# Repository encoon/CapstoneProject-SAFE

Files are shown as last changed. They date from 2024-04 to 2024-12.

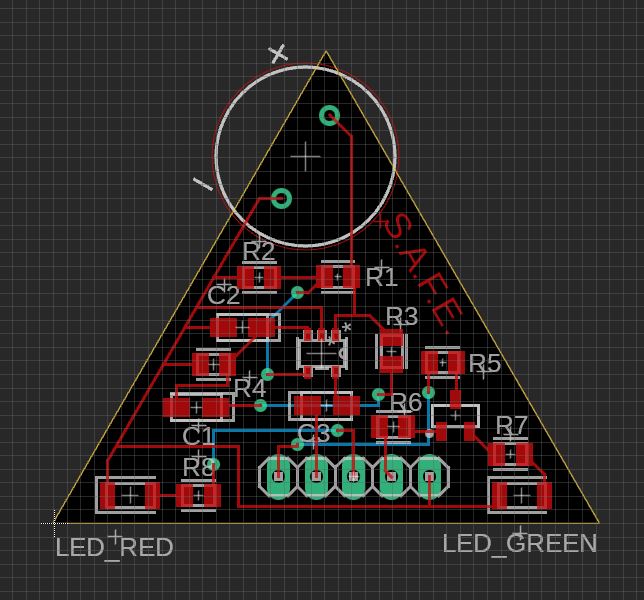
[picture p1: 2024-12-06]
AdditionalParts/AlarmingCircuitPCBDesign/Screenshot_AlarmingCircuit_PCB.JPG

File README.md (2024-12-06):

# CapstoneProject-SAFE
University of Utah capstone project, team SAFE repository<br/>
Project started in Feb 2024.
Demo day on 12/06 2024.

## Content
Team SAFE has been made up for a project making a product that determines the fatigue point of the muscle. We are using an EMG sensor from a company called 'Myoware', using sesnor Myoware 2.0. The fatigue point gets calculated by using fatigue coefficient by using raspberry pi 4, a grove base hat inverter, and alerts the user with a designed alerting circuit PCB. Refer to the block diagram below.

## Architecture Diagram
Diagram of the Block Diagram

### Members
Taehoon Kim<br/>
Nicholas Eloff<br/>
Thomas Green<br/>
Inhyup Lee

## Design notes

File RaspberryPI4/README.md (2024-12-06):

This folder contains the following files:
    Actual python codes for the project
    Text file that are helpful with the python codes
    raspberrypi datasheet

Authors: Taehoon Kim, Nicholas Eloff, Thomas Green, and Inhyup Lee
Date: December 06, 2024

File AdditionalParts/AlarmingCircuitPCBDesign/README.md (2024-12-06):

This folder contains the following files:
    screenshots of the schematic & PCB
    alarming circuit shcematic in .fsch file
    alarming circuit PCB in .fbrd file
    receipt zip file

Authors: Taehoon Kim, Nicholas Eloff, Thomas Green, and Inhyup Lee
Date: December 06, 2024

.fsch and .fbrd files should be opened in Fusion360.

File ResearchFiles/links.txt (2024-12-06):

What is EMG? Hackaday.io
https://hackaday.io/project/8823-super-simple-muscle-emg-sensor/details

An EMG Patch for the Real-Time Monitoring of Muscle-Fatigue Conditions During Exercise
https://pmc.ncbi.nlm.nih.gov/articles/PMC6679275/

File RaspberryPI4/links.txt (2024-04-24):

* Raspberry Pi

* Grove Base Hat
    -Grove Base Hat Wiki
    https://wiki.seeedstudio.com/Grove_Base_Hat_for_Raspberry_Pi/

    -Example Code for EMG
    https://forum.seeedstudio.com/t/emg-sensor-and-raspberri-pi/258793

* EMG Sensor Implementation
    -With Arduino youtube video
    https://www.youtube.com/watch?v=0FsTPQY1bJw&ab_channel=SaravananAL

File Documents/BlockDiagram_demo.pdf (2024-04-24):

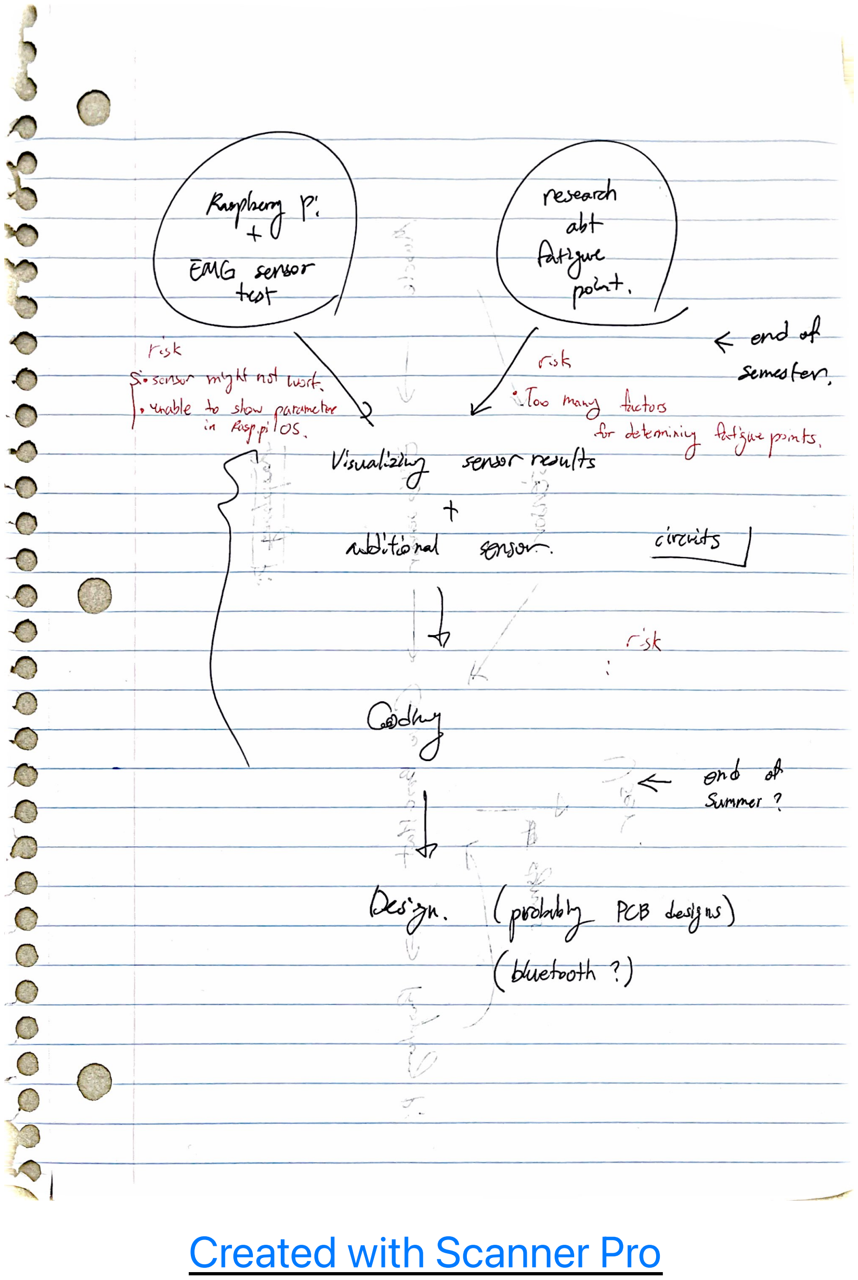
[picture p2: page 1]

EMG sersor

research
ast

pokt.

rusk
ssans myt no Wst.

K end of

semester,
lo mary tutos
sersor neultsAr dtoniy taga pinbs.
Viualaty
Mditoral | circrits

5sk

Colly
ond o

Sumner ?

(prdity Pee boyu)

Created with Scanner Pro (https://apple.co/3zkbMwu)

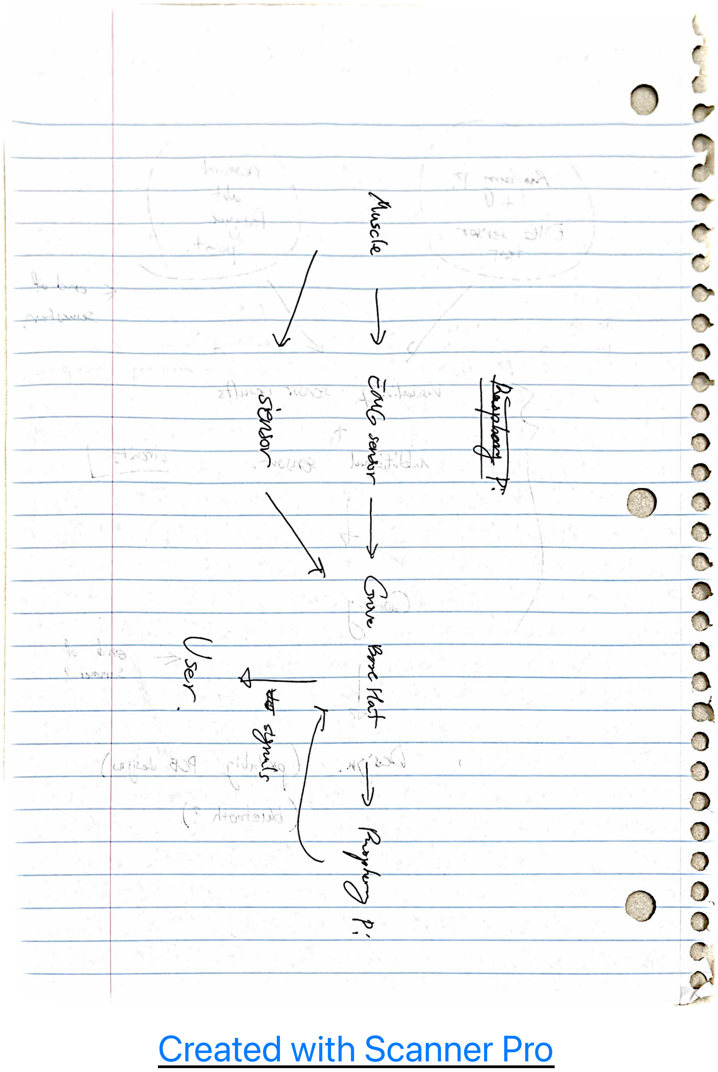
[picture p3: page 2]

Pripboy P:

Musele -> andser-

SONor

~ Ge Bore Hat:
User,

Rpkg P;

Created with Scanner Pro (https://apple.co/3zkbMwu)

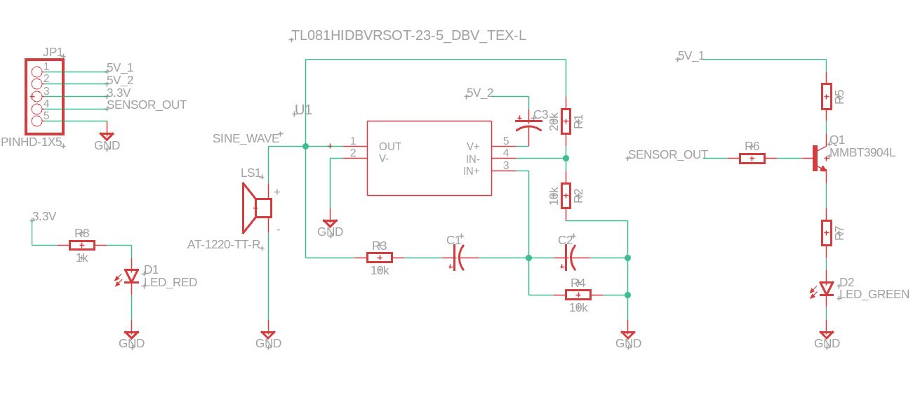
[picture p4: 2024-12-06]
AdditionalParts/AlarmingCircuitPCBDesign/Screenshot_AlarmingCircuit_Schematic.JPG

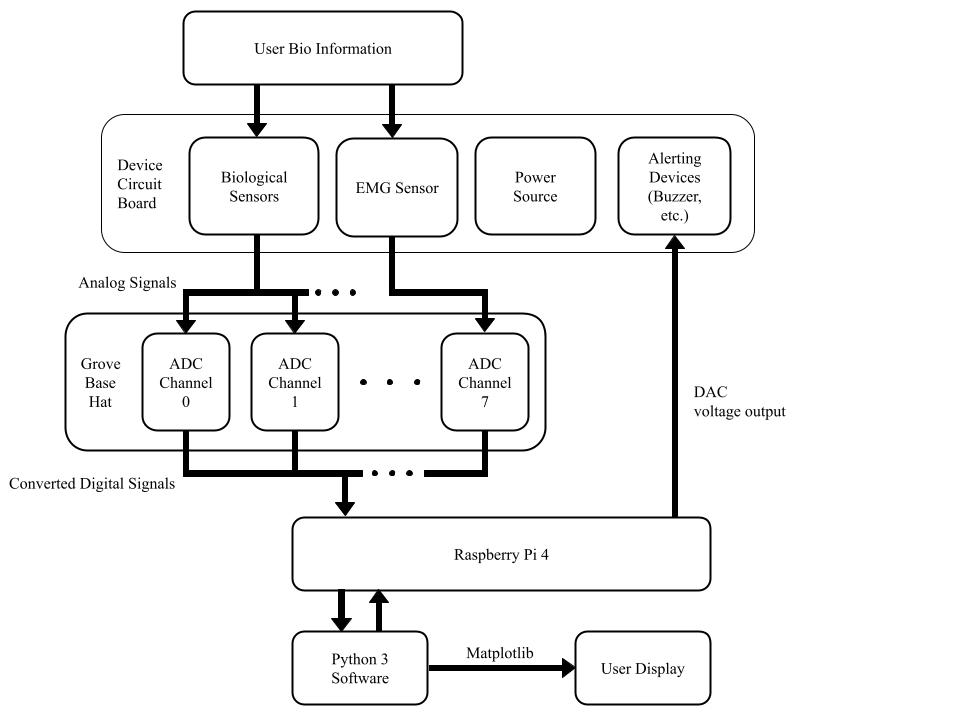
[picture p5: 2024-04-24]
Documents/SAFE_Block_Diagram.jpg

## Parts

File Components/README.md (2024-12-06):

This folder contains the following files:
    Datasheets folder for datasheet of the EMG sensor(myoware v1, myoware 2.0)
    Bills of Material for this project

Authors: Taehoon Kim, Nicholas Eloff, Thomas Green, and Inhyup Lee
Date: December 06, 2024

All information of components being used will be in this folder.

Check BoM file to see the datasheets for each components. Schematic is in AdditionalParts>AlarmingCircuitPCBDesign.

Prefer opening .CSV file with Excel.

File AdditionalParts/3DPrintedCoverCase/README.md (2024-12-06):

This folder contains the following files:
    gcode file of 3D schematic
    stl file 3D schematic
    .DS_Store
    
Authors: Taehoon Kim, Nicholas Eloff, Thomas Green, and Inhyup Lee
Date: December 06, 2024

Design files for cover case will be saved in this folder. (Additional explanation down here.)

1. Circuit_case.stl (generated from "Fusion 360"): It contains the 3D geometry of the circuit case in STL format. It provides detailed information about the model, including its dimensions, volume, surface area, and mesh details. The model is watertight, making it suitable for 3D printing, but it contains some concave features.

2. Circuit_Case.gcode (generated from "PrusaSlicer"): It is the G-code file with specific machine instructions for 3D printing the circuit case. This file includes paths for extrusion, travel movements, and layer-by-layer instructions optimized for FDM printers. It is ready to be used directly with a compatible 3D printer (Marriott library 3d printer).

After slicing the stl file in slicer software, must ensure the G-code file is compatible with specific 3D printer model and adjust settings based on the material being used or set the bundle file which is designed to use with specific 3D printer.

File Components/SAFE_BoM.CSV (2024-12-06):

Part | Quantity | Mouser/Digikey Part # | Manufacturer Part # | Manufacturer | Short Description | Footprint/Package | Datasheet
D1 | 1 | 754-1165-1-ND | APTL3216SURCK | Kingbright | LED RED CLEAR CHIP SMD | 1206 SMD | https://www.kingbrightusa.com/images/catalog/SPEC/APTL3216SURCK.pdf
D2 | 1 | 754-1162-1-ND | APTL3216CGCK | Kingbright | LED GREEN CLEAR CHIP SMD | 1206 SMD | https://www.kingbrightusa.com/images/catalog/SPEC/APTL3216CGCK.pdf
R1, R2, R3, R4 | 5 | 311-10KERCT-ND | RMCF0805FT10K0 | Stackpole Electronics Inc | RES 10K OHM 1% | 0805 SMD | https://www.seielect.com/catalog/sei-rmcf_rmcp.pdf
R5, R8 | 2 | RMCF0805JT1K10CT-ND | RMCF0805JT1K10 | Stackpole Electronics Inc | RES 1.1K OHM 5% | 0805 SMD | https://www.taiwansemi.com/products/datasheet/RS2AA%20SERIES_G14.pdf
R6, R7 | 2 | 311-620ARCT-ND | RC0805JR-07620RL | YAGEO | RES 620 OHM 5% | 0805 SMD | https://www.yageo.com/upload/media/product/products/datasheet/rchip/PYu-RC_Group_51_RoHS_L_12.pdf
C1, C2 | 2 | C1206C104K5RAC7210 | 399-C1206C104K5RAC7210CT-ND | KEMET | CAP CER 0.1UF | 1206 (3216 Metric) | https://content.kemet.com/datasheets/KEM_C1002_X7R_SMD.pdf
C3 | 1 | 1206B103K500CT | 1292-1600-1-ND | Walsin Technology Corporation | CAP CER 10000PF | 1206 (3216 Metric) | https://www.passivecomponent.com/wp-content/uploads/datasheet/WTC_MLCC_General_Purpose.pdf
Q1 | 1 | MMBT3904LT1G | MMBT3904LT1GOSCT-ND | onsemi | TRANS NPN 40V 0.2A SOT23-3 | SOT 23-3 | https://www.onsemi.com/pdf/datasheet/mmbt3904lt1-d.pdf
U1 | 1 | TL081HIDBVR | 296-TL081HIDBVRCT-ND | Texas Instruments | IC OPAMP JFET 1 CIRCUIT SOT23-5 | SOT 23-5 | https://www.ti.com/general/docs/suppproductinfo.tsp?distId=10
U2 | 1 | AT-1220-TT-R | 668-1097-ND | PUI Audio, Inc. | BUZZER MAGNETIC 1.5V 12MM TH

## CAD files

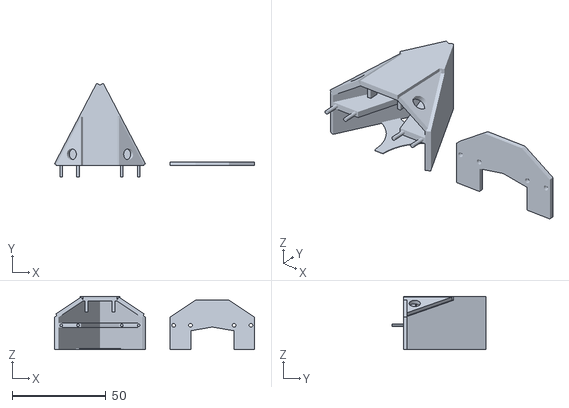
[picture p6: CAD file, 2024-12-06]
AdditionalParts/3DPrintedCoverCase/stl/Circuit_case.stl
106.8 x 49.9 x 28.3

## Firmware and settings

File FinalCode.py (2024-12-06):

import time, sys, math, pywt, random
import RPi.GPIO as GPIO
import numpy as np
from matplotlib import pyplot as plt
from matplotlib import animation
from grove.adc import ADC                                                                           # type: ignore

__all__ = ["EMGTEST"]

class EMGTEST(object):
    def __init__(self, channel):
        self.channel = channel
        self.adc = ADC()

    @property
    def value(self):
        return self.adc.read(self.channel)


Grove = EMGTEST


def main():

    GPIO.setmode(GPIO.BCM)
    GPIO.setup(14, GPIO.OUT)
    GPIO.setwarnings(False)
    pwm = GPIO.PWM(14, 1200)
    from grove.helper import SlotHelper                                                             #type: ignore
    sh = SlotHelper(SlotHelper.ADC)
    pin = sh.argv2pin()

    sensor = EMGTEST(pin)

    #Holds multiple COB, WSD, and FC calculations
    COB_Arr = []
    WSD_Arr = []
    FC_Arr = []
    sens_arr = []

    while True:
        #print("Current Voltage % is: {}".format(sensor.value/10))

        if(len(sens_arr) < 100):
            sens_arr.append(sensor.value)
            #print("Sensor Value: {}".format(sensor.value))
        else:
            #Grab Wavelet Coefficient (w)
            w = pywt.downcoef('a', sens_arr, 'db2')
            #print("Wavelete coefficients: {}".format(w))
            #print("Wavelete coefficients: {}".format(w))
            sens_arr = []

            if(len(COB_Arr)<30): #51 is arbitrary number chosen until testing is done
                #Get sum of wavelet coefficients
                w_sum = 0
                for n in w:
                    w_sum+=abs(n)

                #Get length of w, Note that this isn't the L that should be used, this is a place holder
                
###
###             # L is not the length of the wavelet coefficient array! 
###
                
                L = 12

                #Calculate Wavelet Center of Balance (COB)
                #COB = 1/(sum_1^L(|w_k|))*sum_1^L(|w_k|*(2^{L-k}-1))
                #Calculate Wavelet Standard Deviation (WSD)
                #WSD = sqrt((sum_k^L(|w_k|*(L-k-COB^2)))/(sum_1^L(w_k)))
                if(w_sum!=0):
                    cob_sum = 0
                    wsd_sum = 0
                    count = 0
                    for n in w:
                        count+=1
                        cob_sum += abs(n)*(2**(L-count)-1)
                        #print("cob_sum using L-count: {}".format(cob_sum))
                        #print("current w_sum is: {}".format(w_sum))
                        #print("L-count: {}".format(L-count))
                    COB = cob_sum/w_sum
                    COB_Arr.append(COB)
                    #print("COB: {}".format(COB))

                    count = 0
                    for n in w:
                        count+=1
                        wsd_sum+=abs(n)*(L-count-COB)**2
                    WSD_Arr.append(math.sqrt(abs(wsd_sum/w_sum)))
                    #print("WSD: {}".format(math.sqrt(abs(wsd_sum/w_sum))))
                else:
                    COB_Arr.append(0)
                    WSD_Arr.append(0)
            else:
                #Calculate Center of Balance Transition (ICOB)
                #ICOB = sqrt((1/N)sum_1^N((COB - avg(COB))^2))
                avg_COB = sum(COB_Arr)/(len(COB_Arr)-1)

                ICOB_sum = 0
                for n in COB_Arr:
                    ICOB_sum += abs(n-avg_COB)
                ICOB = math.sqrt((1/len(COB_Arr)*ICOB_sum))
                #print("ICOB: {}".format(ICOB))

		        #Reset COB_Arr
                COB_Arr = []

		        #Calculate Muscular Tissue Effeciency (ME)
		        #ME = avg(|WSD - avg(WSD)|)
                avg_WSD = sum(WSD_Arr)/(len(WSD_Arr)-1)
                WSD_sum = 0
                for n in WSD_Arr:
                    WSD_sum += abs(n - avg_WSD)
                ME = WSD_sum/len(WSD_Arr)
                #print("ME: {}".format(ME))

                #Reset WSD_Arr
                WSD_Arr = []

		        #Add Fatigue Coefficiant
                FC_Arr.append(ME*ICOB)
                #print("FC: {}".format(ME*ICOB))
                #print("Current Voltage % is: {}".format(sensor.value/10))
	
	        #Check if we have enough fatigue coefficients to test the average difference
	        #If the average difference is low enough, alert the user their muscles are fatigued
            if(len(FC_Arr) > 5): #10 is an arbitrary number chosen until testing is done
                last_FC = FC_Arr[0]
                AVG_Diff = []
                for n in range(1,6):
                    AVG_Diff.append(abs(FC_Arr[n]-last_FC))
                    last_FC = FC_Arr[n]

                print("Current AVG Diff is: {}".format(sum(AVG_Diff)/len(AVG_Diff)))

                #NOTE: Following values are from simulation using range of random values - may need to be adjusted for sensor
                #If taking ~50 values from sensor, Avg Diff must be somewhere around 50
                #If taking ~100 or ~1000 values, go <15
                #If taking ~250 or ~500 values, go <10
                #If taking ~750 values, go <12
                if(sum(AVG_Diff)/(len(AVG_Diff))<50): #using placeholder until testing gives us better values to use, need to change <1
                    print("Fatigued Muscle")
                    pwm.start(50.0)
                    time.sleep(1.5)
                    pwm.stop()
                else:
                    GPIO.output(14, GPIO.LOW)
                
                AVG_Diff = []
                FC_Arr = []




if __name__ == '__main__':
    main()

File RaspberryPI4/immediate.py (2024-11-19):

import time, sys, math, pywt
import RPi.GPIO as GPIO
from grove.adc import ADC  # type: ignore
import matplotlib.pyplot as plt
from matplotlib.animation import FuncAnimation
from threading import Thread
from collections import deque

__all__ = ["EMGTEST"]

class EMGTEST(object):
    def __init__(self, channel):
        self.channel = channel
        self.adc = ADC()

    @property
    def value(self):
        return self.adc.read(self.channel)

Grove = EMGTEST

# Graphing data storage with deque for optimized fixed-size buffer
COB_graph = deque(maxlen=50)
WSD_graph = deque(maxlen=50)
FC_graph = deque(maxlen=50)
EMG_graph = deque(maxlen=50)

# Graph setup
fig, axs = plt.subplots(4, 1, figsize=(10, 8))
plt.subplots_adjust(hspace=0.5)

def update_plot(frame):
    for ax in axs:
        ax.clear()

    # Plot each graph with reduced complexity
    axs[0].plot(COB_graph, label="COB", color="blue")
    axs[0].set_title("Center of Balance (COB)")
    axs[0].set_ylim(0, 500) 
    axs[0].legend()
    axs[0].grid(False)  # Disable grid for faster rendering

    axs[1].plot(WSD_graph, label="WSD", color="orange")
    axs[1].set_title("Wavelet Standard Deviation (WSD)")
    axs[0].set_ylim(0, 500) 
    axs[1].legend()
    axs[1].grid(False)

    axs[2].plot(FC_graph, label="Fatigue Coefficient (FC)", color="red")
    axs[2].set_title("Fatigue Coefficient (FC)")
    axs[0].set_ylim(0, 500) 
    axs[2].legend()
    axs[2].grid(False)

    axs[3].plot(EMG_graph, label="EMG value (EMG)", color="yellow")
    axs[3].set_title("EMG Graph")
    axs[0].set_ylim(0, 1000) 
    axs[3].legend()
    axs[3].grid(False)

    plt.tight_layout()

def main_logic():
    GPIO.setmode(GPIO.BCM)
    GPIO.setup(4, GPIO.OUT)
    from grove.helper import SlotHelper  # type: ignore
    sh = SlotHelper(SlotHelper.ADC)
    pin = sh.argv2pin()

    sensor = EMGTEST(pin)

    # Holds multiple COB, WSD, and FC calculations
    COB_Arr = []
    WSD_Arr = []
    FC_Arr = []
    sens_arr = []

    while True:
        if len(sens_arr) < 100:
            sens_arr.append(sensor.value)
            EMG_graph.append(sensor.value)
            
            time.sleep(0.005)  # Add slight delay to reduce CPU usage
        else:
            # Grab Wavelet Coefficient (w)
            w = pywt.downcoef('a', sens_arr, 'db2')
            sens_arr = []

            if len(COB_Arr) < 30:
                w_sum = 0
                w_sum = sum(abs(n) for n in w)
                L = 12  # Placeholder for L

                if w_sum != 0:
                    cob_sum = 0
                    wsd_sum = 0
                    count = 0
                    cob_sum = sum(abs(n) * (2**(L - count - 1) - 1) for count, n in enumerate(w))
                    COB = cob_sum / w_sum
                    COB_Arr.append(COB)
                    COB_graph.append(COB)

                    count = 0

                    wsd_sum = sum(abs(n) * (L - count - COB)**2 for count, n in enumerate(w))
                    WSD = math.sqrt(abs(wsd_sum / w_sum))
                    WSD_Arr.append(WSD)
                    WSD_graph.append(WSD)
                else:
                    COB_Arr.append(0)
                    WSD_Arr.append(0)
                    COB_graph.append(0)
                    WSD_graph.append(0)
            else:
                avg_COB = sum(COB_Arr) / (len(COB_Arr) - 1)
                ICOB_sum = 0
                ICOB_sum = sum(abs(n - avg_COB) for n in COB_Arr)
                ICOB = math.sqrt((1 / len(COB_Arr)) * ICOB_sum)
                COB_Arr = []
  
                avg_WSD = sum(WSD_Arr) / (len(WSD_Arr) - 1)
                WSD_sum = 0
                WSD_sum = sum(abs(n - avg_WSD) for n in WSD_Arr)
                ME = WSD_sum / len(WSD_Arr)
                WSD_Arr = []

                FC = ME * ICOB
                FC_Arr.append(FC)
                FC_graph.append(FC)

                if len(FC_Arr) > 5:
                    last_FC = FC_Arr[0]
                    AVG_DIFF = []
                    for n in range(1,6):
                        AVG_Diff.append(abs(FC_Arr[n] - last_FC))
                        last_FC = FC_Arr[n]
                    if sum(AVG_Diff) / len(AVG_Diff) < 75:
                        print("Fatigued Muscle")
                        GPIO.output(4, GPIO.HIGH)
                    else:
                        GPIO.output(4, GPIO.LOW)

                    AVG_Diff = []
                    FC_Arr = []

ani = FuncAnimation(fig, update_plot, interval=100, blit=True)  # Update every 2 seconds with blit enabled

if __name__ == '__main__':
    # Run main logic in a separate thread
    thread = Thread(target=main_logic, daemon=True)
    thread.start()

    # Show the graph
    plt.show()

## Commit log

2024-04-23 EMG Sensor Datasheet uploaded
2024-10-21 Fixed Sum Error
    Fixed incorrect formatting of w_sum in COB and WSD calculations
    [EMG_Data_Transfer_v1.py]
2024-10-22 Added Array of Sensor Values
    Added an array to contain the sensor values to properly calculate the fatigue coefficients.
2024-10-22 Produces output
    Code now occasionally hits current output. Must be updated to produce output on hardware.
2024-10-22 Corrected wavelet code
    Wavelet coefficients had incorrect method
    [EMG_Data_Transfer_v1.py]
2024-10-24 Added print messages to check the AVG_diff
2024-11-11 PCB Zip file for ordering
2024-11-14 Update EMG_Data_Transfer_v2.py
    Corrected array initializations. Added notes about approximate average difference.
    [EMG_Data_Transfer_v2.py]
2024-11-19 New Threshold
    Threshold for average difference increased to 75, currently best known value.
    Bug fixes regarding average difference calculation
    [EMG_Data_Transfer_v2.py]
2024-11-19 thread func added
2024-11-19 Update EMG_Data_Transfer_v2.py
    Fixed value error
    [EMG_Data_Transfer_v2.py]
2024-12-06 3d printer
    [Circuit_case.stl]
2024-12-06 Organized files
    [Circuit_case.stl]
2024-12-06 File upload for Additional components of project
    [Circuit_case.stl]
2024-12-06 Updated README files
    [SAFE_BoM.CSV]
